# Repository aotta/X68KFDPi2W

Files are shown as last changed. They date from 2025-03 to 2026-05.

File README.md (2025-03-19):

# X68KFDPi2W
X68KFDPi2W - Floppies drive emulator All-In-One for Sharp X68000

The design is an evolution of my previous X68KFDPico, and allows the two drives of the X68000 to be emulated both externally and internally connected. The engine of the emulator are two Raspberry Pico, one ‘normal’ to handle the special floppy signals and the other ‘W’ to emulate the floppies, SDcard image management and a simple web server to choose the disks to be inserted in the floppies.
Ejection and insertion of the disks can be done via the two keys in the X68KFDPi2W or by connecting the cables of the original floppy keys (in case they are not present internally). The same for the internal LEDs, which are however replicated in the emulator (only the green one, the red LED is managed only for the internal one).
Floppies images format supported are "HDM" and "HFE". 
Writing to floppy is not supported yes (may be in future...)

A special thanks to Adafruit team for their great "Floppy library", from wich i starded for floppy emulation part.

**NOTE** Last revision fix a conflicts found when using both an internal and an external X68KFDPi2W for 4 floppy emulation, now disabled 74LVC245 when drives not enabled. 
Please use last PCB, X68KFDPico.u2f and X68KFDPi2W.u2f version!!

**NOTE 2** Some games need tricks to properly boot, for example A-JAX works when starting with both drive off (leds off). When using 2HDboot.x for launching games from HD, you must "insert" floppy 1 & 2 pushing buttons when 2hdboot starts, then "eject" pushing again button after few seconds.

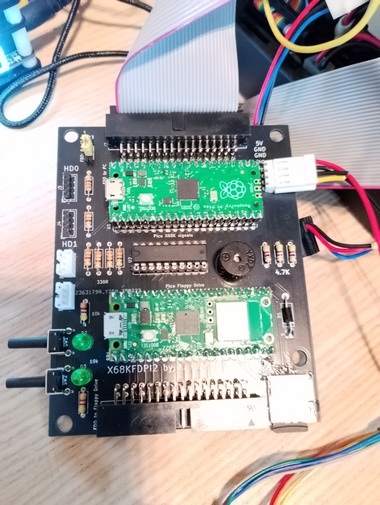
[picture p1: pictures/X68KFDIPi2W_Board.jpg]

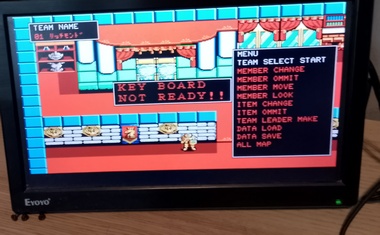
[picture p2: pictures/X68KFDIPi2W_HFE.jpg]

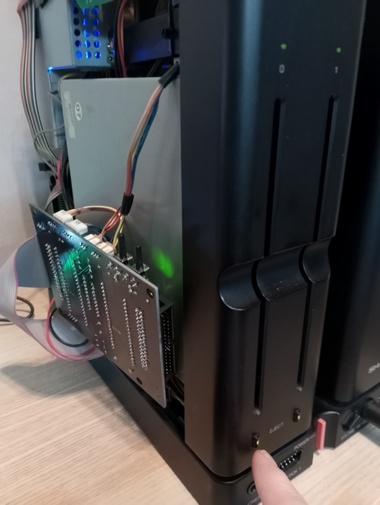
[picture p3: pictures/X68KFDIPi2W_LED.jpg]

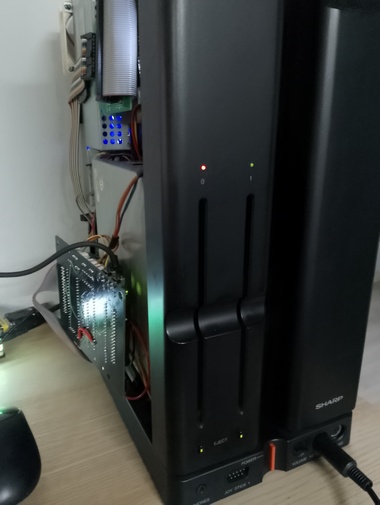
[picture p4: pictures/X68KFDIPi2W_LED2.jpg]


You need to add a "wifi.cfg" in root of your SDcard, with this 4 text row:
SSID
WIFI PASSWORD
Default floppy in drive 0
Default floppy in drive 1

The 2 lines related to the default floppys can be omitted and changed everytime via Web server.
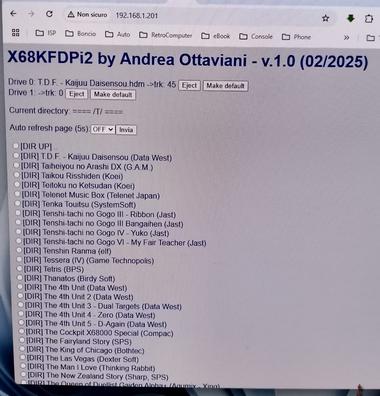
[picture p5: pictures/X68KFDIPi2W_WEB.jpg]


Gerbers file are provided for the PCB, add you pico clone, and flash the firmware ".uf2" in the Pico and in the Pico W by connecting it while pressing button on Pico and drop it in the opened windows on PC.

For any comments or questions about the projects, please use the official thread in the forum: https://nfggames.com/forum2/index.php?topic=7512.0

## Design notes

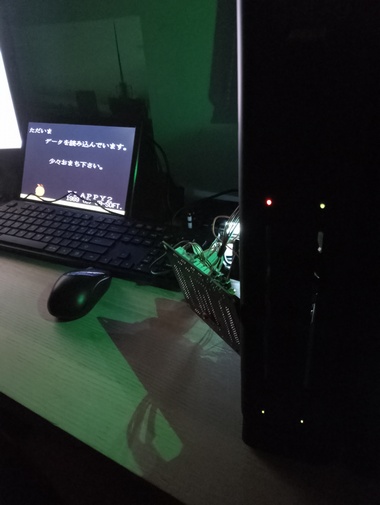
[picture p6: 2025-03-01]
pictures/X68KFDIPi2W_LED3.jpg

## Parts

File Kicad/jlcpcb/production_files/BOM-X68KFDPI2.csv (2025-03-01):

Comment | Designator | Footprint | LCSC | Quantity
Pico | U1 | Raspberry_Pi_PicoW_SMT_THT |  | 1
PicoW | RP1 | Raspberry_Pi_PicoW_SMT_THT |  | 1
LedFD0 | J7 | JST_PH_B3B-PH-K_1x03_P2.00mm_Vertical |  | 1
R330 | R2 | R_Axial_DIN0207_L6.3mm_D2.5mm_P10.16mm_Horizontal |  | 1
10k | R7 | R_Axial_DIN0207_L6.3mm_D2.5mm_P7.62mm_Horizontal |  | 1
R330 | R5 | R_Axial_DIN0207_L6.3mm_D2.5mm_P10.16mm_Horizontal |  | 1
FD01 | J4 | JST_PH_B4B-PH-K_1x04_P2.00mm_Vertical |  | 1
FloppyPWR | J9 | PinHeader_1x04_P2.54mm_Horizontal |  | 1
R330 | R1 | R_Axial_DIN0207_L6.3mm_D2.5mm_P10.16mm_Horizontal |  | 1
74LVC245 | U2 | DIP-20_W7.62mm_Socket |  | 1
10k | R8 | R_Axial_DIN0207_L6.3mm_D2.5mm_P7.62mm_Horizontal |  | 1
R330 | R4 | R_Axial_DIN0207_L6.3mm_D2.5mm_P10.16mm_Horizontal |  | 1
R330 | R3 | R_Axial_DIN0207_L6.3mm_D2.5mm_P10.16mm_Horizontal |  | 1
4.7K | R9 | R_Axial_DIN0207_L6.3mm_D2.5mm_P7.62mm_Horizontal |  | 1
HxC Connector | J1 | IDC-Header_2x17_P2.54mm_Horizontal |  | 1
4.7K | R10 | R_Axial_DIN0207_L6.3mm_D2.5mm_P7.62mm_Horizontal |  | 1
4.7K | R11 | R_Axial_DIN0207_L6.3mm_D2.5mm_P7.62mm_Horizontal |  | 1
FD Int/Ext (0,1/2,3) | J13 | PinHeader_1x03_P2.54mm_Vertical |  | 1
LED | D3 | LED_D3.0mm |  | 1
1N5817 | D1 | D_DO-15_P12.70mm_Horizontal |  | 1
FD Ext Connector | J2 | IDC-Header_2x17_P2.54mm_Horizontal |  | 1
SW_Push | SW1 | SW_Tactile_SPST_Angled_PTS645Vx83-2LFS |  | 1
LedFD1 | J8 | JST_PH_B3B-PH-K_1x03_P2.00mm_Vertical |  | 1
Buzzer | BZ1 | Buzzer_12x9.5RM7.6 |  | 1
Micro_SD_Card | J11 | J_SD_Card-micro_socket_A |  | 1
SW_Push | SW2 | SW_Tactile_SPST_Angled_PTS645Vx83-2LFS |  | 1
FD00 | J3 | JST_PH_B4B-PH-K_1x04_P2.00mm_Vertical |  | 1
LED | D2 | LED_D3.0mm |  | 1
R330 | R6 | R_Axial_DIN0207_L6.3mm_D2.5mm_P10.16mm_Horizontal |  | 1

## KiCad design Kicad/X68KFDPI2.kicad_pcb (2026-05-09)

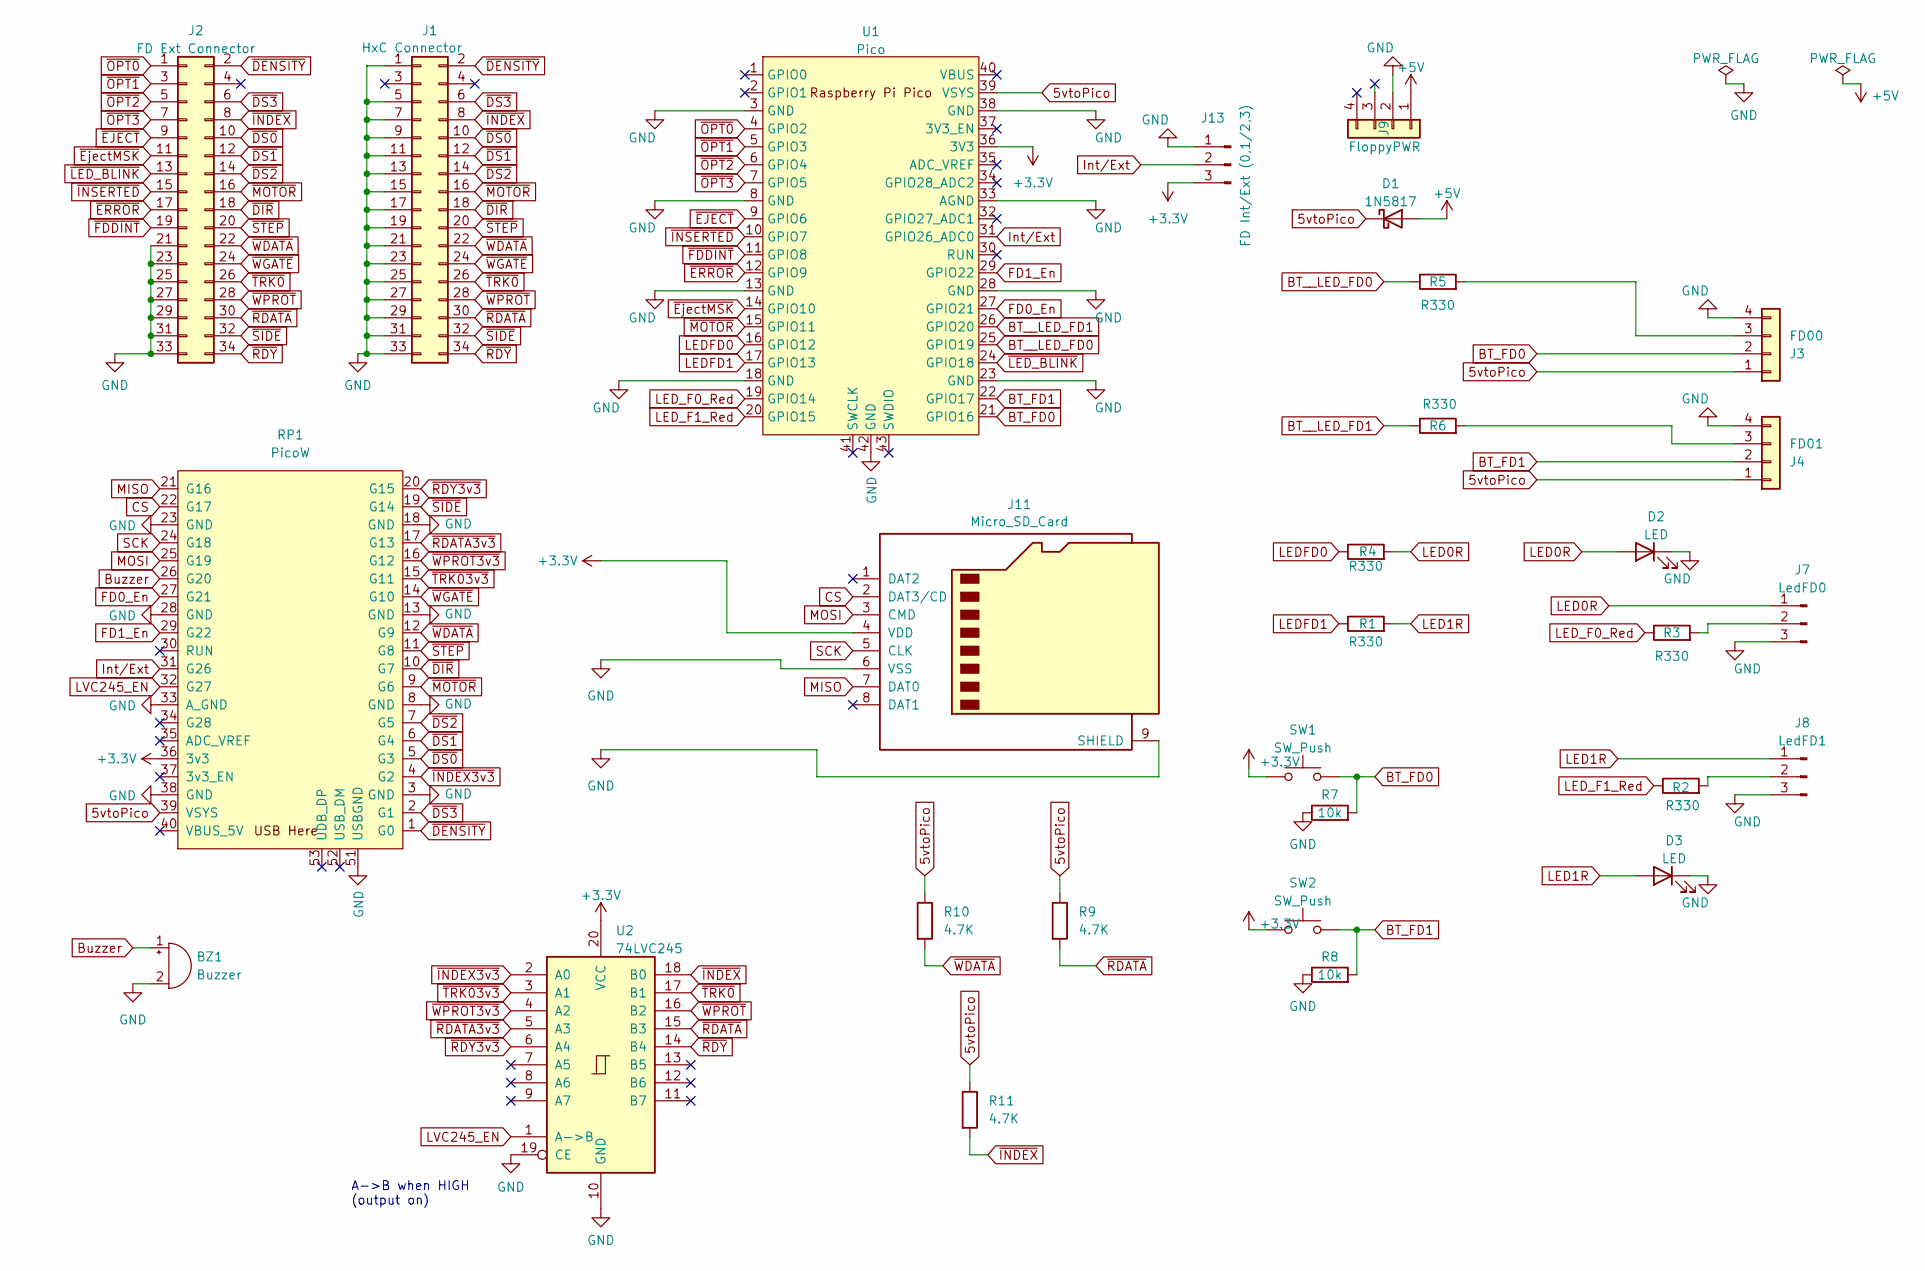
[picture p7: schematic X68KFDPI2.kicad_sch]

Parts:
BZ1: Buzzer; Buzzer_12x9.5RM7.6
D1: 1N5817; D_DO-15_P12.70mm_Horizontal
D2, D3: LED; LED_D3.0mm
J1: HxC Connector; IDC-Header_2x17_P2.54mm_Horizontal
J2: FD Ext Connector; IDC-Header_2x17_P2.54mm_Horizontal
J3: FD00; JST_PH_B4B-PH-K_1x04_P2.00mm_Vertical
J4: FD01; JST_PH_B4B-PH-K_1x04_P2.00mm_Vertical
J7: LedFD0; JST_PH_B3B-PH-K_1x03_P2.00mm_Vertical
J8: LedFD1; JST_PH_B3B-PH-K_1x03_P2.00mm_Vertical
J9: FloppyPWR; PinHeader_1x04_P2.54mm_Horizontal
J11: Micro_SD_Card; J_SD_Card-micro_socket_A
J13: FD Int/Ext (0,1/2,3); PinHeader_1x03_P2.54mm_Vertical
R1, R2, R3, R4, R5, R6: R330; R_Axial_DIN0207_L6.3mm_D2.5mm_P10.16mm_Horizontal
R7, R8: 10k; R_Axial_DIN0207_L6.3mm_D2.5mm_P7.62mm_Horizontal
R9, R10, R11: 4.7K; R_Axial_DIN0207_L6.3mm_D2.5mm_P7.62mm_Horizontal
RP1: PicoW; Raspberry_Pi_PicoW_SMT_THT
SW1, SW2: SW_Push; SW_Tactile_SPST_Angled_PTS645Vx83-2LFS
U1: Pico; Raspberry_Pi_PicoW_SMT_THT
U2: 74LVC245; DIP-20_W7.62mm_Socket

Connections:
5vtoPico: D1.1 (K), J3.1, J4.1, R9.1, R10.1, R11.1, RP1.39 (VSYS), U1.39 (VSYS)
+3.3V: J11.4 (VDD), J13.3, RP1.36 (3v3), SW1.1, SW2.1, U1.36 (3V3), U2.20 (VCC)
+5V: D1.2 (A), J9.1
BT_FD0: J3.2, R7.2, SW1.2, U1.21 (GPIO16)
BT_FD1: J4.2, R8.2, SW2.2, U1.22 (GPIO17)
BT__LED_FD0: R5.1, U1.25 (GPIO19)
BT__LED_FD1: R6.1, U1.26 (GPIO20)
Buzzer: BZ1.1 (+), RP1.26 (G20)
CS: J11.2 (DAT3/CD), RP1.22 (G17)
FD0_En: RP1.27 (G21), U1.27 (GPIO21)
FD1_En: RP1.29 (G22), U1.29 (GPIO22)
GND: BZ1.2 (-), D2.1 (K), D3.1 (K), J1.1, J1.5, J1.7, J1.9, J1.11, J1.13, J1.15, J1.17, J1.19, J1.21, J1.23, J1.25, J1.27, J1.29, J1.31, J1.33, J2.21, J2.23, J2.25, J2.27, J2.29, J2.31, J2.33, J3.4, J4.4, J7.3, J8.3, J9.2, J11.6 (VSS), J11.9 (SHIELD), J13.1, R7.1, R8.1, RP1.3 (GND), RP1.8 (GND), RP1.13 (GND), RP1.18 (GND), RP1.23 (GND), RP1.28 (GND), RP1.33 (A_GND), RP1.38 (GND), RP1.51 (USBGND), U1.3 (GND), U1.8 (GND), U1.13 (GND), U1.18 (GND), U1.23 (GND), U1.28 (GND), U1.33 (AGND), U1.38 (GND), U1.42 (GND), U2.10 (GND), U2.19 (CE)
Int/Ext: J13.2, RP1.31 (G26), U1.31 (GPIO26_ADC0)
LED0R: D2.2 (A), J7.1, R4.2
LED1R: D3.2 (A), J8.1, R1.2
LEDFD0: R4.1, U1.16 (GPIO12)
LEDFD1: R1.1, U1.17 (GPIO13)
LED_F0_Red: R3.1, U1.19 (GPIO14)
LED_F1_Red: R2.1, U1.20 (GPIO15)
LVC245_EN: RP1.32 (G27), U2.1 (A->B)
MISO: J11.7 (DAT0), RP1.21 (G16)
MOSI: J11.3 (CMD), RP1.25 (G19)
unnamed: J3.3, R5.2
unnamed: J4.3, R6.2
unnamed: J7.2, R3.2
unnamed: J8.2, R2.2
SCK: J11.5 (CLK), RP1.24 (G18)
~DENSITY: J1.2, J2.2, RP1.1 (G0)
~DIR: J1.18, J2.18, RP1.10 (G7)
~DS0: J1.10, J2.10, RP1.5 (G3)
~DS1: J1.12, J2.12, RP1.6 (G4)
~DS2: J1.14, J2.14, RP1.7 (G5)
~DS3: J1.6, J2.6, RP1.2 (G1)
~EJECT: J2.9, U1.9 (GPIO6)
~ERROR: J2.17, U1.12 (GPIO9)
~EjectMSK: J2.11, U1.14 (GPIO10)
~FDDINT: J2.19, U1.11 (GPIO8)
~INDEX3v3: RP1.4 (G2), U2.2 (A0)
~INDEX: J1.8, J2.8, R11.2, U2.18 (B0)
~INSERTED: J2.15, U1.10 (GPIO7)
~LED_BLINK: J2.13, U1.24 (GPIO18)
~MOTOR: J1.16, J2.16, RP1.9 (G6), U1.15 (GPIO11)
~OPT0: J2.1, U1.4 (GPIO2)
~OPT1: J2.3, U1.5 (GPIO3)
~OPT2: J2.5, U1.6 (GPIO4)
~OPT3: J2.7, U1.7 (GPIO5)
~RDATA3v3: RP1.17 (G13), U2.5 (A3)
~RDATA: J1.30, J2.30, R9.2, U2.15 (B3)
~RDY3v3: RP1.20 (G15), U2.6 (A4)
~RDY: J1.34, J2.34, U2.14 (B4)
~SIDE: J1.32, J2.32, RP1.19 (G14)
~STEP: J1.20, J2.20, RP1.11 (G8)
~TRK0: J1.26, J2.26, U2.17 (B1)
~TRK03v3: RP1.15 (G11), U2.3 (A1)
~WDATA: J1.22, J2.22, R10.2, RP1.12 (G9)
~WGATE: J1.24, J2.24, RP1.14 (G10)
~WPROT3v3: RP1.16 (G12), U2.4 (A2)
~WPROT: J1.28, J2.28, U2.16 (B2)

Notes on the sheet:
A->B when HIGH (output on)

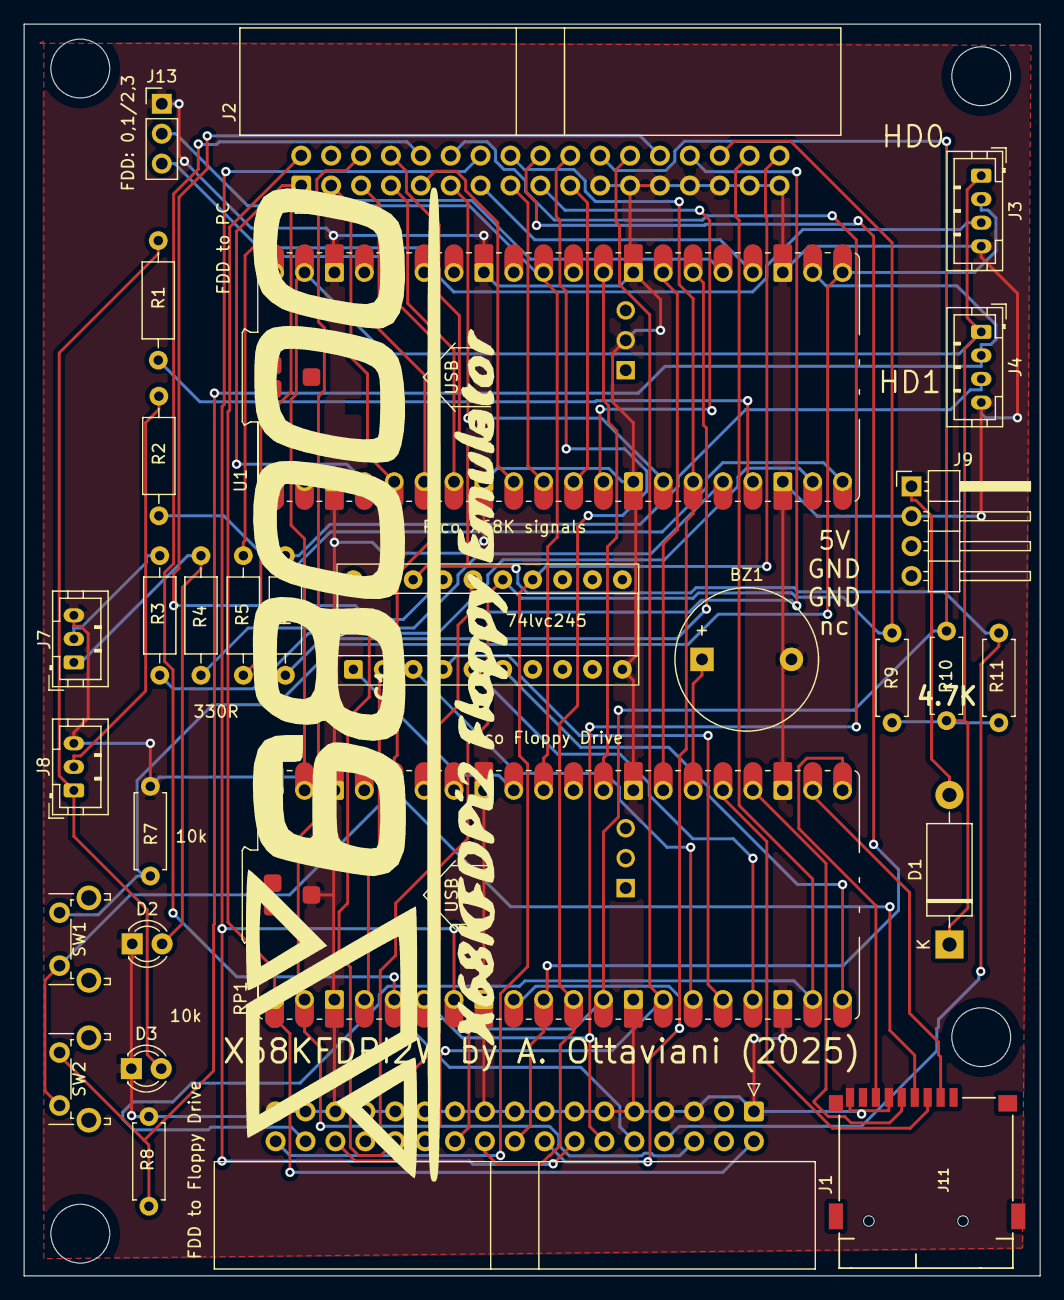
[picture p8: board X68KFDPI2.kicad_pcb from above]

Board: 2 copper layers, 86.3 x 106.4 mm, 31 parts (1 on the bottom side), 58 nets.

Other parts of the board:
G1: LOGO; X68Klogo
Gback: LOGO; X68Klogo

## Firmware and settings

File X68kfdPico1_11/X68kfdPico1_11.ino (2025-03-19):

/*
 * X68KFDINO - External FD adapter for Sharp X68000
 * by Andrea Ottaviani june 2023
 * 
 * 
Access/Write strobe :

/OPTION_SEL_X : "Chip select" for the extra functions of drive DSX (X: 0-3)

Input / functions signals :

/EJECT_FUNC : If this signal is low when OPTION_SEL_X is asserted, the disk will be ejected.
/LOCK_FUNC (Eject MSK?): If this signal is low when OPTION_SEL_X is asserted, the disk will be locked (eject button off). If this signal is high when OPTION_SEL_X is asserted the disk will be unlocked (eject button on).
/BLINK_FUNC : If this signal is low when OPTION_SEL_X is asserted, the LED blink. If this signal is high when OPTION_SEL_X is asserted, the LED stop blinking.

Output signals (drive status):

/DISK_IN_DRIVE : when OPTION_SEL_X is asserted : Low = a disk in the drive. High = No disk.
/INSERT_FAULT : when OPTION_SEL_X is asserted : Low = a disk insert failure occured . High = No problem. This status is cleared at the rising edge of OPTION_SEL_X.

Output signal (Interrupt line):

/INT : Interrupt line : This signal is activated at each disk status change (inserted/ejected). The interrupt is cleared at the rising edge of /OPTION_SEL_X. (Note : more than one drive can activate this line in the same time -> Softwares scan all disk drive at each /INT assertion).

Note 1: For proper operation all output should be able to drive 5/150=33mA since 150 ohms pull-up are used.
Note 2: The X68000 /OPTION_SEL_X assertion duration is ~2.5us per access. This can depend of the software, the CPU speed.
 */


//#define WAIT_SERIAL

#ifdef USE_TINYUSB
#include <Adafruit_TinyUSB.h>
#endif

//Cablage
#define OPT0                2  // Set D2 as OPT0 Read strobe
#define OPT1                3  // Set D3 as OPT1 Read strobe
#define OPT2                4  // Set D4 as OPT2 Read strobe
#define OPT3                5  // Set D5 as OPT3 Read strobe
#define Eject               6  // Set D6 as Eject Read strobe
#define Inserted            7  // Set D7 as Inserted Read strobe
#define FDDINT              8  // Set D8 as FD Interrupt Read strobe
#define Error               9  // Set D9 as Error Read strobe
#define EjectMSK           10  // Set D10 as EjectMSK Read strobe
#define Motor              11  // Set D11 as Motor Read strobe
#define LEDFD0             12  // Set D12 as LED FD0 output (Green LED)
#define LEDFD1             13  // Set D13 as LED FD1 output (Green LED)
#define LED_FD0_RED        14  // Set D14 as LED FD0 output (Red LED)
#define LED_FD1_RED        15  // Set D15 as LED FD1 output (Red LED)
#define BT_FD0             16  // Set D16 as Button FD0 Read strobe
#define BT_FD1             17  // Set D17 as Button FD1 Read strobe
#define LED_BLINK          18  // Set A0 as LED (Blink) output
#define BT_FD0_INT         19  // Set D19 as Button FD0 Read strobe from internal floppy
#define BT_FD1_INT         20  // Set D20 as Button FD1 Read strobe from internal floppy
#define DF0_EN             21  // Set D20 as Button FD1 Read strobe from internal floppy
#define DF1_EN             22  // Set D20 as Button FD1 Read strobe from internal floppy
#define INTLED             25  // Set D20 as Button FD1 Read strobe from internal floppy
#define INTEXT             26  // Set D20 as Button FD1 Read strobe from internal floppy

void setup() {
  pinMode(OPT0, INPUT_PULLUP);
  pinMode(OPT1, INPUT_PULLUP);
  pinMode(OPT2, INPUT_PULLUP);
  pinMode(OPT3, INPUT_PULLUP);
  pinMode(Eject, INPUT_PULLUP);
  pinMode(BT_FD0, INPUT);
  pinMode(BT_FD1, INPUT);
  pinMode(LED_BLINK, INPUT_PULLUP); // Blink
  pinMode(EjectMSK, INPUT_PULLUP); // LOCK (Red led)
  pinMode(Motor, INPUT_PULLUP); // 
  pinMode(Inserted, OUTPUT);
  pinMode(Error, OUTPUT);
  pinMode(FDDINT, OUTPUT);
  pinMode(LEDFD0, OUTPUT);
  pinMode(LEDFD1, OUTPUT);
  pinMode(LED_FD0_RED, OUTPUT); // used for LED LOCK, Red light
  pinMode(LED_FD1_RED, OUTPUT); // used for LED LOCK, Red light
  pinMode(BT_FD0_INT, OUTPUT);
  pinMode(BT_FD1_INT, OUTPUT);
  pinMode(DF0_EN, OUTPUT);
  pinMode(DF1_EN, OUTPUT);
  pinMode(INTLED,OUTPUT);
  pinMode(INTEXT,INPUT);


#if defined(WAIT_SERIAL)
 Serial.begin(115200);
  while (!Serial) {
  }
  Serial.println("Serial connected");
#endif


}

void loop() {
  unsigned char DF0=0; // 0=eject, 1=insert, 2=lock, 3=blink
  unsigned char DF1=0; // 0=eject, 1=insert, 2=lock, 3=blink
  unsigned char bitBlink0=0;
  unsigned char bitBlink1=0;
  unsigned char OPTA;
  unsigned char OPTB;
  
  digitalWriteFast(LED_FD0_RED,LOW);
  digitalWriteFast(LED_FD1_RED,LOW);
      
  digitalWrite(Inserted,HIGH);
  digitalWrite(DF0_EN,LOW);
  digitalWrite(DF1_EN,LOW);
  
  unsigned int BlinkCounter=0;
    if (digitalRead(INTEXT)) {
    //if(1) { //(1) to force drive 0/1 - use (0) to force drive 2/3
      OPTA=OPT0;
      OPTB=OPT1;
      Serial.print("Drive 0/1");
    } else {
      OPTA=OPT2;
      OPTB=OPT3;
      Serial.print("Drive 2/3");
    }


  // put your main code here, to run repeatedly:
  Serial.println("Start");


  while(1) {

    BlinkCounter++;
    if (BlinkCounter>=200000) BlinkCounter=0;
    
    if (digitalRead(BT_FD0)) {
        digitalWrite(FDDINT,LOW);
       if (DF0==1) {
        DF0=0;
       } else {
        bitBlink0=0;
        DF0=1;
        digitalWrite(INTLED,LOW);
         }
    Serial.print("DF0:");Serial.println(DF0);
    delay(300);
    }
   
  if (digitalRead(BT_FD1)) {
      digitalWrite(FDDINT,LOW);
        if (DF1==1) {
        DF1=0;
        } else {
        bitBlink1=0;
        DF1=1;
        digitalWrite(INTLED,LOW);
       }
    Serial.print("DF1:");Serial.println(DF1);
    delay(300);
    }
   

////////////////// OPT 0 //////////////////
  if (!digitalReadFast(OPTA)) {
    //Serial.print("opt0");

    if (!digitalReadFast(Eject)) {   // era Eject
       digitalWriteFast(Inserted,HIGH);
       DF0=0;
       digitalWriteFast(FDDINT,LOW);  // not remove!! era HIGH     
       Serial.println("Ej 0-");
       digitalWrite(DF0_EN,LOW);
       delay(4);
       digitalWrite(INTLED,HIGH);
       digitalWriteFast(LED_FD0_RED,LOW);
   }    
    
    if (!digitalReadFast(EjectMSK)) {
        digitalWriteFast(LED_FD0_RED,HIGH);
        digitalWriteFast(LEDFD0,LOW);
        Serial.println("EjMSK 0-");
    } else {
    //    digitalWriteFast(LED_FD0_RED,LOW);  
    }

    if (!digitalReadFast(LED_BLINK)) {
      //  Serial.println("blink 0-");
       bitBlink0=1;
      }   

    if (!DF0) {
        digitalWriteFast(Inserted,HIGH);  // for TT!!  
        digitalWriteFast(FDDINT,HIGH);
        digitalWriteFast(Error,HIGH);  
        digitalWriteFast(DF0_EN,LOW);
        digitalWrite(LED_FD0_RED,LOW);
    } else {
        digitalWriteFast(Inserted,LOW);
        digitalWriteFast(FDDINT,HIGH);  // not remove!! era HIGH
        digitalWriteFast(Error,HIGH);  
        digitalWriteFast(DF0_EN,HIGH);
        bitBlink0=0;
        if (!digitalRead(Motor)) digitalWrite(LED_FD0_RED,HIGH);
      }

 }  // opt 0


////////////////// OPT 1 //////////////////
 if (!digitalReadFast(OPTB)) {
   // Serial.print("opt1");
   
    if (!(digitalReadFast(Eject))) { // era eject
      Serial.print("Ej 1-"); 
      digitalWriteFast(Inserted,HIGH);   
      digitalWriteFast(FDDINT,LOW);  // not remove!! era HIGH
      DF1=0;
      digitalWrite(DF1_EN,LOW);
      delay(4);
      digitalWrite(INTLED,HIGH);
      digitalWriteFast(LED_FD1_RED,LOW);
    }
      
    if (!digitalReadFast(EjectMSK)) {
      digitalWriteFast(LED_FD1_RED,HIGH);
      digitalWriteFast(LEDFD1,LOW);
      Serial.print("EjMSK 1-");
      } else {
     //   digitalWriteFast(LED_FD1_RED,LOW);  
    }

    if (!digitalReadFast(LED_BLINK)) {
     // Serial.println("blink 1-");
      bitBlink1=1;
      }   

    if (!DF1) {
        digitalWriteFast(Inserted,HIGH);  // for TT!!  
        digitalWriteFast(FDDINT,HIGH);  //NOT REMOVE FOR EJECT DRIVE LOW!!!
        digitalWriteFast(Error,HIGH);  
        digitalWriteFast(DF1_EN,LOW);
        digitalWrite(LED_FD1_RED,LOW);
      } else {
        digitalWriteFast(Inserted,LOW);
        digitalWriteFast(FDDINT,HIGH);  // not remove!! era HIGH
        digitalWriteFast(Error,HIGH);
        digitalWriteFast(DF1_EN,HIGH);  
        bitBlink1=0;
        if (!digitalRead(Motor)) digitalWrite(LED_FD1_RED,HIGH);
      }

  } //opt1

  if (!DF0) {
        digitalWriteFast(LEDFD0,LOW);
        digitalWriteFast(BT_FD0_INT,LOW);
      } else {
         digitalWriteFast(LEDFD0,HIGH);
         digitalWriteFast(BT_FD0_INT,HIGH);
      }
  if (!DF1) {
        digitalWriteFast(LEDFD1,LOW);
        digitalWriteFast(BT_FD1_INT,LOW);
        digitalWrite(LED_FD1_RED,LOW);
      } else {
         digitalWriteFast(LEDFD1,HIGH);
         digitalWriteFast(BT_FD1_INT,HIGH);
       }

  if (bitBlink0) {
    //   delay(6);
      if (BlinkCounter>=34000) {
        //Serial.print(".");
        digitalWrite(LEDFD0,LOW);
        digitalWrite(BT_FD0_INT,LOW);
       } else {
        digitalWrite(LEDFD0,HIGH);
        digitalWrite(BT_FD0_INT,HIGH);
       }
    }
  if (bitBlink1) {
      //Serial.print("b1"); // do not remove, needed for timing
    if (BlinkCounter>=60000) {
        digitalWriteFast(LEDFD1,LOW);
        digitalWriteFast(BT_FD1_INT,LOW);
       } else {
        digitalWriteFast(LEDFD1,HIGH);
         digitalWriteFast(BT_FD1_INT,HIGH);
      }
    }
    if (digitalRead(Motor)) {
      digitalWrite(LED_FD0_RED,LOW);
      digitalWrite(LED_FD1_RED,LOW); 
    }
  digitalWrite(Inserted,LOW); //for 2HDboot
  } //while
 
}

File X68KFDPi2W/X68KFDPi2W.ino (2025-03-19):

/////////////////////////////////////////////////////////////////////////////////////////
// X68KFDPI2W a floppy emulator AIO for Sharp X68000 by Andrea Ottaviani (c) 02/2025   //
// thanks to Adafruit for its great floppy library !!                                  
//
/////////////////////////////////////////////////////////////////////////////////////////

//#define WAIT_SERIAL
//#define WAIT_WIFI
bool HFE0_On=false,HFE1_On=false;   

#include "drive.pio.h"

#include "SdFat.h"
#include "pitches.h"
// SD_FAT_TYPE = 0 for SdFat/File as defined in SdFatConfig.h,
// 1 for FAT16/FAT32, 2 for exFAT, 3 for FAT16/FAT32 and exFAT.
#define SD_FAT_TYPE 1
#include <WiFi.h>
#include <WiFiClient.h>
#include <WebServer.h>
#include <LEAmDNS.h>
#include <StreamString.h>

#define DENSITY_PIN    0  // IDC 2
#define SELECT_PIN3    1  // IDC 6  DRIVE SELECT DS3
#define INDEX_PIN      2  // IDC 8   // output from PicoFloppy
#define SELECT_PIN0    3  // IDC 10 DRIVE SELECT DS0
#define SELECT_PIN1    4  // IDC 12 DRIVE SELECT DS1
#define SELECT_PIN2    5  // IDC 14 DRIVE SELECT DS2
#define MOTOR_PIN      6  // IDC 16
#define DIR_PIN        7  // IDC 18
#define STEP_PIN       8  // IDC 20
#define WRDATA_PIN     9  // IDC 22 //input for reading from PC when writing SD
#define WRGATE_PIN    10  // IDC 24 // input for writing on disk
#define TRK0_PIN      11  // IDC 26 // output from PicoFloppy
#define PROT_PIN      12  // IDC 28 // output from PicoFloppy
#define READ_PIN      13  // IDC 30 // output from PicoFloppy
#define SIDE_PIN      14  // IDC 32
#define READY_PIN     15  // IDC 34  // output from PicoFloppy
#define BUZZER_PIN    20  // Output pin for sound
#define DF0_EN        21  // Info for drive A enabled from other PICO
#define DF1_EN        22  // Info for drive B enabled from other PICO
#define INTEXT        26  // Read from jumper - FD0-1 when HIGH, FD2-3 when LOW
#define LVC245_EN     27  // Enable output to FD bus when HIGH


char ssid[40];
char password[40];
char filename0[128];
char filename1[128];
int curtrack0=0;
int curtrack1=0;
bool subdirOn=false;
bool refreshOn=false;
int SELECT_PINA, SELECT_PINB;
int numdrv0,numdrv1;

// SDCARD_SS_PIN is defined for the built-in SD on some boards.
#ifndef SDCARD_SS_PIN
const uint8_t SD_CS_PIN = SS;
#else  // SDCARD_SS_PIN
// Assume built-in SD is used.
const uint8_t SD_CS_PIN = SDCARD_SS_PIN;
#endif  // SDCARD_SS_PIN

// Try max SPI clock for an SD. Reduce SPI_CLOCK if errors occur.
#define SPI_CLOCK SD_SCK_MHZ(40)

// Try to select the best SD card configuration.
//#if HAS_SDIO_CLASS
//#define SD_CONFIG SdioConfig(FIFO_SDIO)
#if  ENABLE_DEDICATED_SPI
#define SD_CONFIG SdSpiConfig(SD_CS_PIN, DEDICATED_SPI, SPI_CLOCK)
#else  // HAS_SDIO_CLASS
#define SD_CONFIG SdSpiConfig(SD_CS_PIN, SHARED_SPI, SPI_CLOCK)
#endif  // HAS_SDIO_CLASS

#if SD_FAT_TYPE == 0
SdFat SD;
File dir;
File file0;
File file1;
File file2;
File tempfile;
#elif SD_FAT_TYPE == 1
SdFat32 SD;
File32 dir;
File32 file0;
File32 file1;
File32 file2;
File32 tempfile;
#elif SD_FAT_TYPE == 2
SdExFat SD;
ExFile dir;
ExFile file0;
ExFile file1;
ExFile file2;
ExFile tempfile;
#elif SD_FAT_TYPE == 3
SdFs SD;
FsFile dir;
FsFile file0;
FsFile file1;
FsFile file2;
FsFile tempfile;
#else  // SD_FAT_TYPE
#error invalid SD_FAT_TYPE
#endif  // SD_FAT_TYPE
char curDir[512]="/";
WebServer server(80);
const int led = LED_BUILTIN;

#define DEBUG_PRINTF(...) Serial.printf(__VA_ARGS__)
#define DEBUG_ASSERT(x)                                                        \
  do {                                                                         \
    if (!(x)) {                                                                \
      Serial.printf(__FILE__ ":%d: Assert fail: " #x "\n", __LINE__);          \
    }                                                                          \
  } while (0)
#include "mfm_impl.h"

enum {
  max_flux_bits = 166667 // 300RPM (200ms rotational time), 1us bit times era 200000  
};
enum { max_flux_count_long = (max_flux_bits + 31) / 32 };

// Data shared between the two CPU cores
volatile int fluxout0; // side number 0/1 or -1 if no flux should be generated
volatile int fluxin0; // side number 0/1 or -1 if no flux should be generated
volatile int fluxout1; // side number 0/1 or -1 if no flux should be generated
volatile int fluxin1; // side number 0/1 or -1 if no flux should be generated
volatile size_t flux_count_long =
    max_flux_count_long; // in units of uint32_ts (longs)
volatile uint32_t flux_data0[2]
                           [max_flux_count_long]; // one track of flux data for
                                                  // both sides of the disk
volatile uint32_t flux_data1[2]
                           [max_flux_count_long]; // one track of flux data for
                                                  // both sides of the disk
volatile uint32_t flux_datain0[2]
                           [max_flux_count_long]; // one track of flux data for
                                                  // both sides of the disk
volatile int wrote0=0;
volatile int writeon0=0;

struct floppy_format_info_t {
  uint8_t cylinders, sectors, sides; // number of sides may be 1 or 2
  uint16_t bit_time_ns;
  size_t flux_count_bit;
  uint8_t n; // sector size is 128<<n
  bool is_fm;
};

const struct floppy_format_info_t format_info[] = {
    {80, 18, 2, 1000, 200000, 2, false}, // 3.5" 1440kB, 300RPM
    {80, 9, 2, 2000, 100000, 2, false},  // 3.5" 720kB, 300RPM

    {80, 15, 2, 1000, 166667, 2, false}, // 5.25" 1200kB, 360RPM
    
    {77, 8, 2, 1000, 166667, 3, false}, // 5.25" 1232kB, 360RPM

    {40, 9, 2, 2000, 100000, 2, false},  // 5.25" 360kB, 300RPM

    {77, 26, 1, 2000, 80000, 0, true}, // 8" 256kB, 360RPM
};

const floppy_format_info_t *cur_format = &format_info[0];
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

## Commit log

2025-03-03 Added 74lvc245 dir control
    Test in progress for avoiding conflict when 2 x68kfdpi2w are used togheter
    [X68KFDPI2-CuBottom.gbr, X68KFDPI2-CuTop.gbr, X68KFDPI2-EdgeCuts.gbr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]
2025-03-03 fixed 4 drive support with 2 X68KFDPi2W
    fixed 4 drive support with 2 X68KFDPi2W (last pcb version required)
    [X68KFDPi2W.ino]
2025-03-03 Add files via upload
    fix
    [X68KFDPi2W.ino]
2025-03-05 Add files via upload
    fix for internal red led
2025-03-10 Fix for drive 0/1-2/3
    [X68KFDPI2.kicad_pcb, X68KFDPI2.kicad_sch]
2025-03-10 Add files via upload
    fix+moved button connectors
2025-03-10 Fix - version with drive number from switch
2025-03-19 fix issue with 2hdboot.x
    [X68KFDPi2W.ino]
2026-05-09 Fixed 5vsb power to gnd in power connector
2026-05-09 Fixed fdd power connector
    Fixed 5vsb to gnd in fdd power connector for some models
    [X68KFDPI2.kicad_pcb, X68KFDPI2.kicad_sch]
2026-11-02 Add write support, D88/DIM images and new web interface
    - Write support for sector images: WRDATA captured by PIO + DMA, sectors
    located from the rotational position (or from the ID field when
    formatting), MFM decoded with the Adafruit Floppy routines, saved to SD
    - Generic track encoder from a sector list (disk_image.h): HDM/XDF, 2HC
    1.2MB, D88 (any 2HD layout), DIM (2HD/2HS/2HC/2HDE/26x256)
    - HFE and read-only files report write protect
    - Web interface: live drive status, one click insert, format tag, logo,
    "Make default" with full path and empty drive, create blank disk
    - Quieter serial log (DEBUG_BUS), RESET_ON_DESELECT option, TRACK 0 output
    follows the selected drive
    - Fix: h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
2026-11-02 Read the INTEXT jumper again to choose drives 0/1 or 2/3
    Remove the debug override that always forced drives 0/1, so a second
    board can emulate drives 2/3 again.
    Claude-Session: https://claude.ai/code/session_0119ZD92MuKxnM7sujE19uER
2026-11-02 Added V.1.1 with write and new fd type
    Added V.1.1 with write and new fd types supported - version Drive0-1 for force drive 0 and 1 selection (otherwise is selected by link in pcb)
2026-11-02 Restore the READY/bus handling of the 03/2025 release
    The write support branch started from a local copy with experimental
    changes: READY and the 74LVC245 outputs followed the disk inserted signals,
    so the drives looked always ready and Dracula hung after loading Human68k.
    - READY low and bus outputs enabled only while an emulated drive is in use
    (motor + select), bus released otherwise (BUS_ON_INSERTED 0)
    - READY no longer forced from the motor signal (READY_FOLLOWS_MOTOR 0)
    - DF0_EN/DF1_EN inputs without pull-down (DF_EN_PULLDOWN 0)
    - TRACK 0 output updated at every step only (TRK0_FOLLOWS_SELECT 0)
    - core 1 starts a revolution only while the drive is selected
    - INTEXT jumper read with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
2026-11-03 Disk change: new eject/insert controller (Pico1 v1.10) and READY pulse on insert
    X68kfdPico1_11 (plain Pico):
    - OPTION_SEL protocol on core 1 in a tight loop (~0.2 us answer)
    - /DISK_IN_DRIVE held until the next access, HIGH when a drive that is not
    ours is addressed (drives 2/3 looked inserted)
    - /INT at every disk change, cleared by the next access, pulsed again every
    100 ms if not served; eject ignored when locked; buttons debounced 30 ms
    - FORCE_DRIVE01 / DIAG options, no delay() or prints inside an access
    X68KFDPi2W (Pico W):
    - READY_PULSE_ON_INSERT: READY low for 50 ms when a disk is inserted, so the
    FDC sees a READY change (Valis II waits for it after the eject)
    - web page: NO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

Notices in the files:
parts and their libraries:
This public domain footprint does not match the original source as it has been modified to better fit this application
